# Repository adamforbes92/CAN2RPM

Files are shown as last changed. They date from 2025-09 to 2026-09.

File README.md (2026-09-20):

# CAN2RPM

ESP32-based converter that reads engine RPM from a CAN bus and outputs a traditional coil-type signal for use with MK1/MK2 analog tachometers.

Built around the ESP32 DevKit V1, it captures VAG/ME7.x CAN messages and translates them into a high-voltage square-wave RPM output suitable for clusters that expect a coil ignition pulse.

**Current firmware version: 1.06** — adopts Forbes Automotive's shared Wi‑Fi AP/mDNS manager, two-step OTA updater and Ignitron dark theme, common across the ESP32 product line.

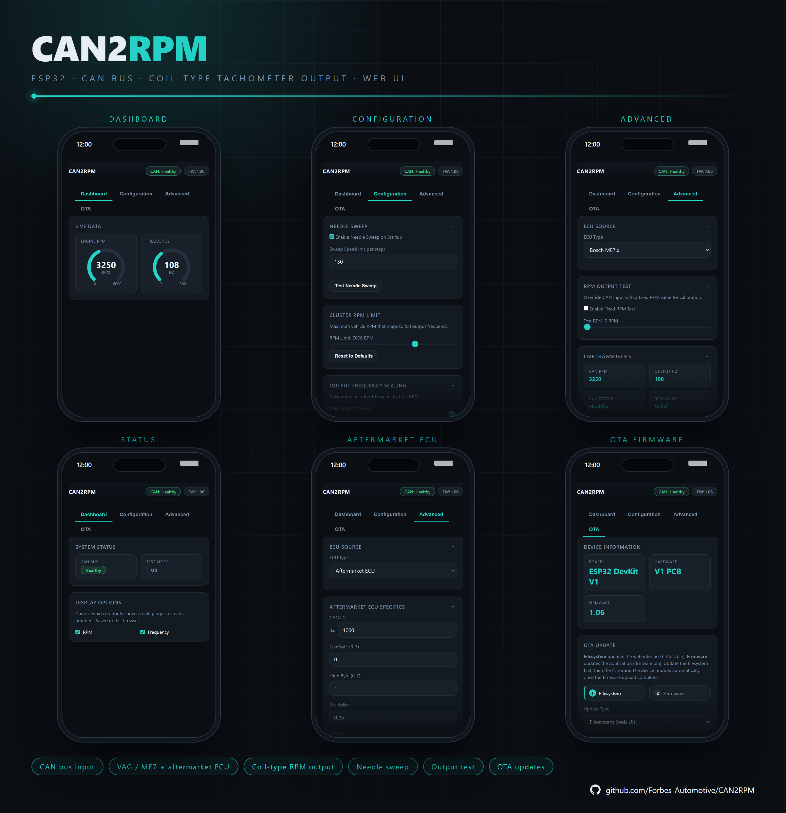
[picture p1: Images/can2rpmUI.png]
CAN2RPM Web UI — dashboard, configuration, advanced, status, aftermarket ECU and OTA


---

## What it does

- Reads **engine RPM** from the chassis CAN bus (500 kbit/s TWAI)
- Outputs a **coil-type RPM signal** on a dedicated pin (high-voltage square wave)
- Supports **aftermarket CAN IDs** with configurable byte mapping and scaling
- Optional **needle sweep** on power-up
- Hosts a **WiFi AP + web UI** for configuration and OTA updates — no laptop or serial cable needed

---

## Hardware

| Function | Detail |
|---|---|
| Board | ESP32 DevKit V1 (`esp32doit-devkit-v1`) |
| CAN transceiver  | SN65HVD230 (3.3 V compatible) |
| RPM output | Coil-type signal on GPIO 26 |
| CAN RX / TX | GPIO 17 / 16 |

---

## Setup

> Connect the module as per the wiring diagram

> Connect to 'CAN2RPM' on WiFi and browse to **192.168.1.1**

> Set the RPM CAN ID and byte positions to match your ECU

> Enable needle sweep if desired

> Save — settings are stored in NVS (EEPROM)

---

## WiFi & Web UI

WiFi is enabled at all times while the unit is powered and a client is connected. Once the last client disconnects the radio turns off automatically (see Power Management below). A power-cycle restores it.

Connect to the **CAN2RPM** access point (open network, `192.168.1.1`) and browse to **192.168.1.1** or **can2rpm.local**.

| Tab | Cards |
|---|---|
| **Dashboard** | **Live Data** — engine RPM and coil output frequency as dial gauges; **System Status** — CAN bus and Test Mode pills; **Display Options** — gauge or numeric per readout |
| **Configuration** | **Needle Sweep** (enable on start-up, ms per step, test button); **Cluster RPM Limit** — the vehicle RPM that maps to full output; **Output Frequency Scaling** — the maximum coil output frequency at full RPM |
| **Advanced** | **ECU Source** — Bosch ME7.x (VAG) or Aftermarket ECU; **Aftermarket ECU Specifics** (shown when Aftermarket is selected) — CAN ID, low / high byte, multiplier and addition; **RPM Output Test** — override the CAN input with a fixed RPM for calibration; **Live Diagnostics** — CAN RPM, output Hz, CAN status and RPM validity |
| **OTA** | Device information and the two-step updater — see below |

<p align="center">
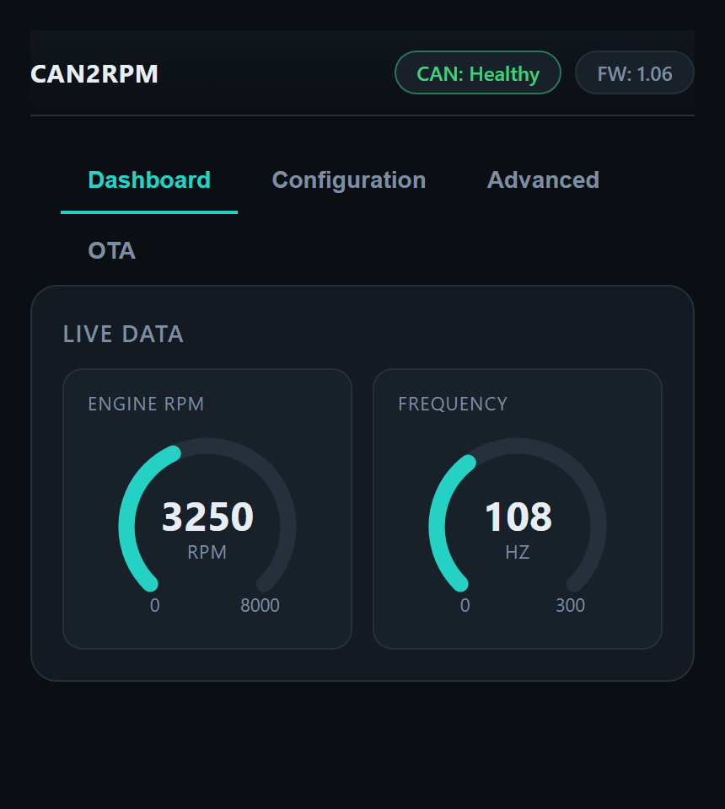
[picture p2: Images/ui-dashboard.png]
Dashboard — engine RPM and output frequency gauges
  
  &nbsp;&nbsp;
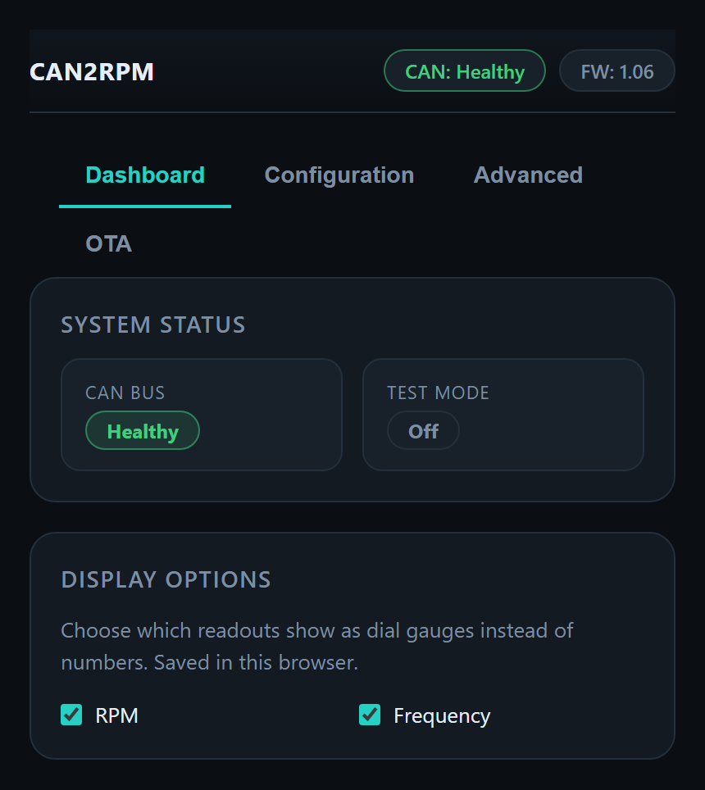
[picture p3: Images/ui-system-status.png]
Dashboard — system status pills (CAN bus, test mode) and display options
  
</p>
<p align="center">
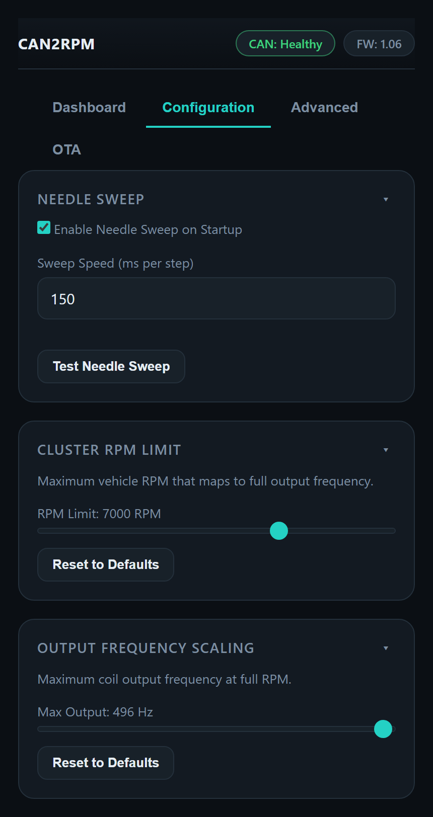
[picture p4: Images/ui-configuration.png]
Configuration — needle sweep, cluster RPM limit and output frequency scaling
  
  &nbsp;&nbsp;
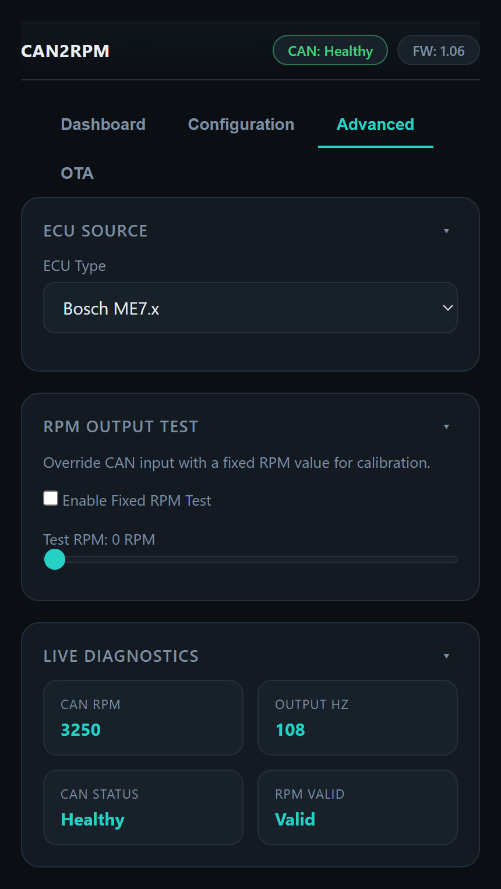
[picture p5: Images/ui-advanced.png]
Advanced — ECU source, RPM output test and live diagnostics
  
</p>
<p align="center">
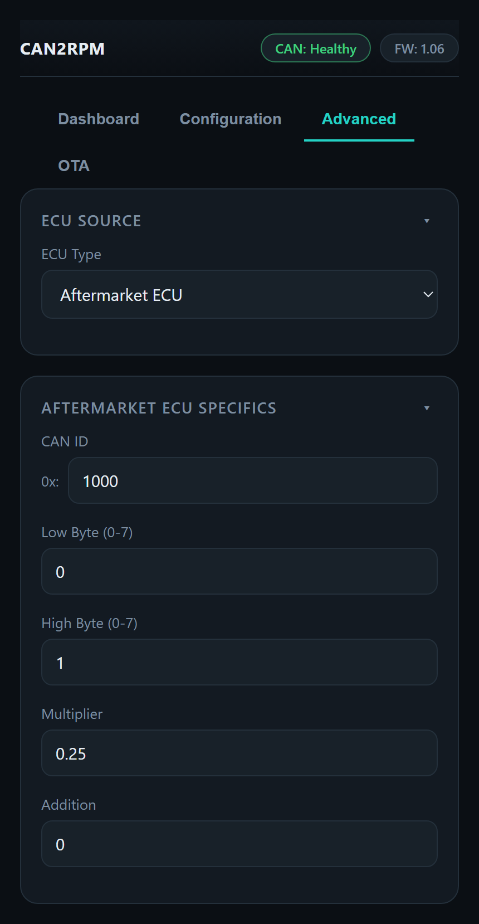
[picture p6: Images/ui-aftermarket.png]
Advanced — ECU source set to Aftermarket ECU, revealing the CAN ID, byte positions, multiplier and addition fields
  
</p>

*Setting the ECU type to **Aftermarket ECU** reveals the byte-mapping card: pick the CAN ID (hex), which two bytes carry RPM, and the multiplier / addition that turn the raw value into RPM.*

### OTA Updates (Two-Step)

CAN2RPM uses Forbes Automotive's shared OTA module. Firmware and web UI are on separate flash partitions, so an update is done in **two steps** from the OTA tab:

1. **Filesystem** — upload `littlefs.bin` (`POST /api/ota/fs`). Updates the web UI (`index.html`, `app.js`, `style.css`). The device does **not** reboot after this step.
2. **Firmware** — upload `firmware.bin` (`POST /api/ota`). Updates the application code and reboots automatically once complete.

The OTA tab shows a "1 Filesystem / 2 Firmware" step indicator so it's clear which upload is in progress. `GET /api/ota/info` reports the running version, board and hardware.

> Download the most recent release `.bin` file(s) from GitHub, connect to CAN2RPM on WiFi, open the OTA tab at 192.168.1.1 (or can2rpm.local), and upload the filesystem image followed by the firmware image.

<p align="center">
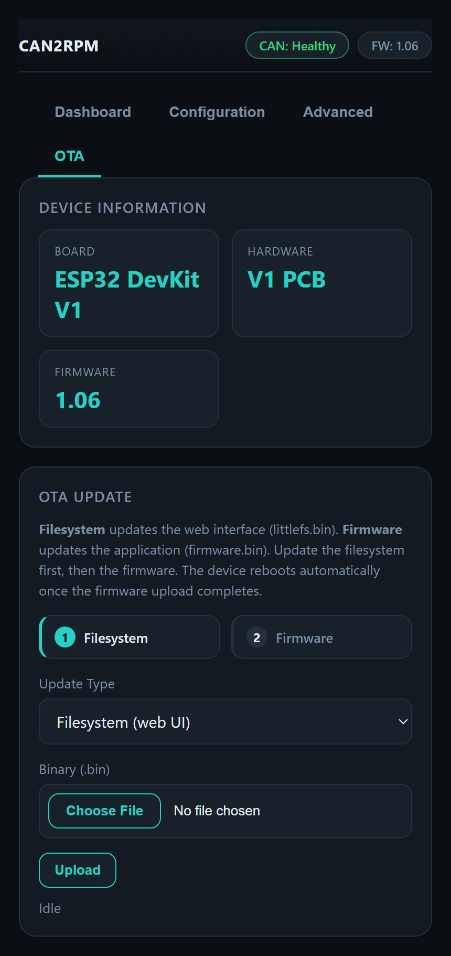
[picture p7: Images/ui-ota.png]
OTA tab — device information and two-step update
  
</p>

---

## Status Indicators

The web UI uses Forbes Automotive's shared dark theme (the same look used across OpenHaldex, Can2Cluster, SpeedPulser, SpeedPulserPro, the MQB Steering Wheel Controller and AirLift Controller), with a consistent colour convention for status pills and badges:

| Colour | Meaning in CAN2RPM |
|---|---|
| 🟢 Green | CAN bus healthy and the displayed RPM/Hz values are live, real data |
| 🔴 Red | CAN bus unhealthy / no signal, or the decoded RPM value isn't yet verified |
| 🟠 Orange | **Test mode is active** — the RPM/Hz readouts are synthetic values generated by the built-in diagnostic test, not real CAN data |

Orange here specifically means "you're looking at test data," so always confirm the Test Mode pill is off before trusting a live reading.

---

## Power Management

The firmware includes a universal reduced-power module that automatically saves current once no clients are connected to the WiFi AP. This directly reduces heat generated by the on-board linear voltage regulator — a linear regulator dissipates heat proportional to `(Vin − Vout) × I_load`, so every milliamp saved is less heat.

**What happens 1 minute after the last client disconnects:**
> WiFi radio off — the single biggest saving (~80–120 mA average)

> CPU frequency scaled: 240 MHz → 80 MHz

> Bluetooth controller disabled at boot (frees ~60 KB RAM)

> Onboard LED off at boot

Everything restores automatically the moment a client reconnects. A power-cycle (ignition off/on) will also bring WiFi back if required.

---

## Build & Flash

PlatformIO project (`platformio.ini`):

```bash
# Build firmware
pio run

# Upload firmware (USB)
pio run -t upload

# Upload web UI (LittleFS)
pio run -t uploadfs
```

---

## Disclaimer

This drives a tachometer but should always be assumed to have some inaccuracy. Forbes Automotive accepts no responsibility for speed or RPM related incidents.

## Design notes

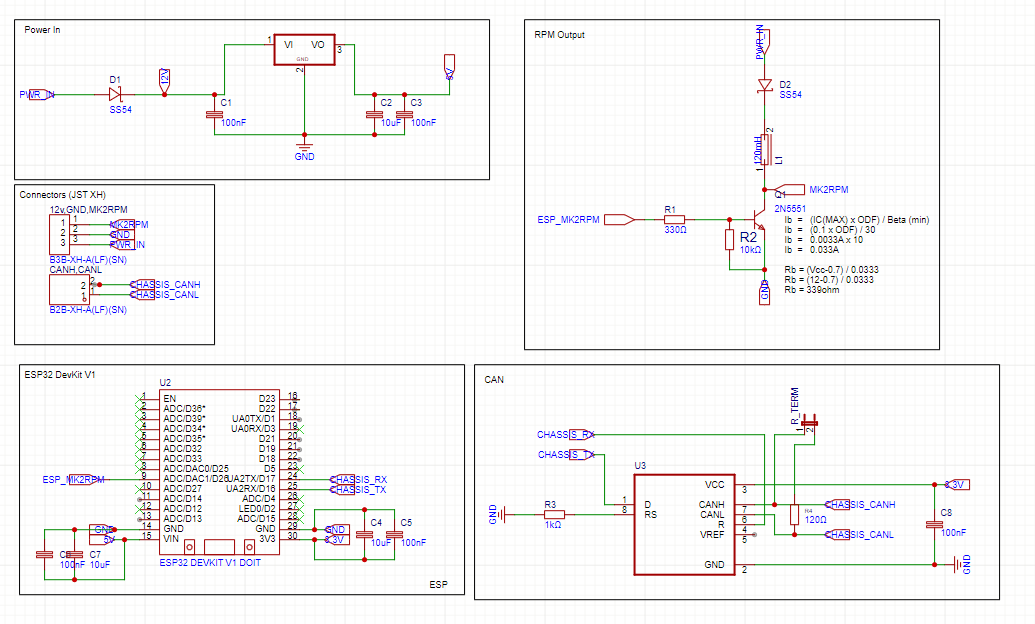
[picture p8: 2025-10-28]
Images/Schematic.png

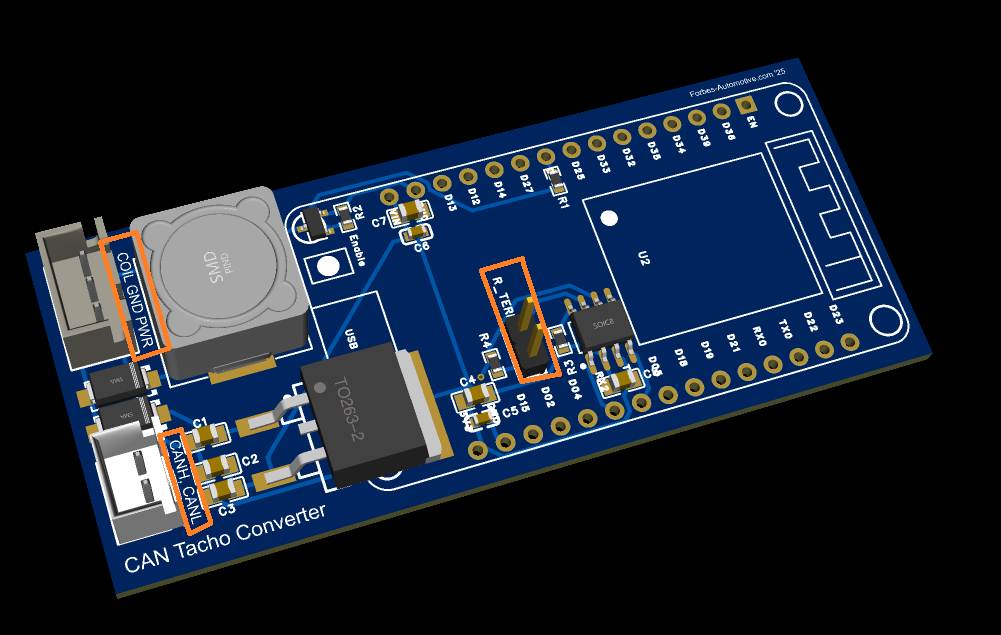
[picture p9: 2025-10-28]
Images/BoardOverview.png

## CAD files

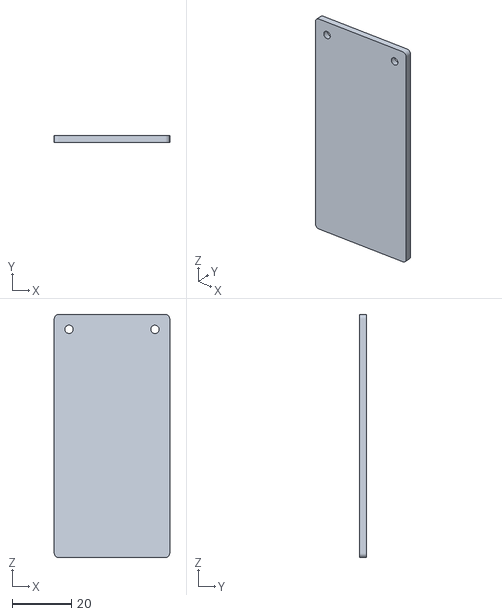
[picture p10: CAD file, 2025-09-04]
Enclosure/Can2RPMLid.STL
39.0 x 2.40 x 82.0

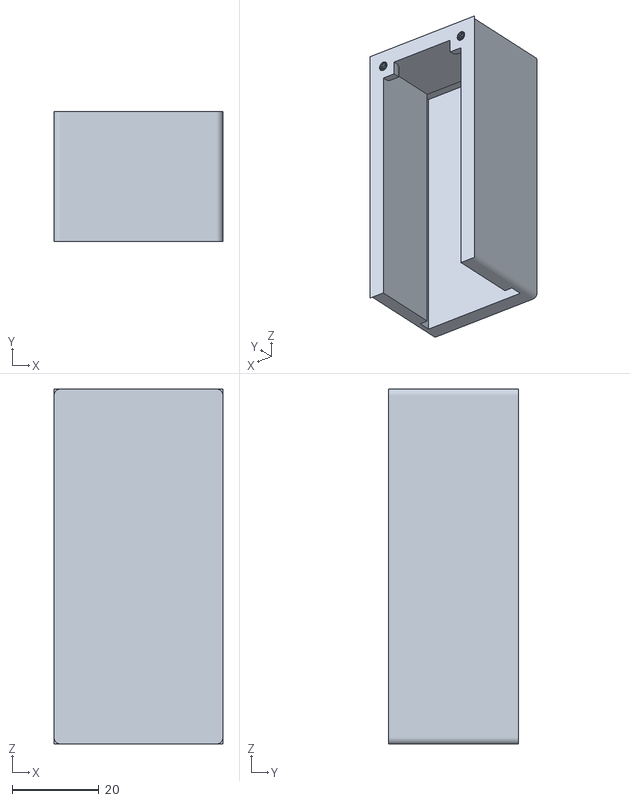
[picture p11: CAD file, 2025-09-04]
Enclosure/Can2RPM.STL
39.0 x 30.0 x 82.0

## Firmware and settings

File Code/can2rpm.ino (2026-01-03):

/* 
Basic CAN-BUS converter to coil based output.  Used for MK2 'analog' clusters in ME7.x and aftermarket conversions.
Forbes-Automotive, 2025
*/

// for CAN
#include "can2rpm_defs.h"
ESP32_CAN<RX_SIZE_256, TX_SIZE_16> chassisCAN;             // CAN Lib
TickTwo tickEEP(writeEEP, eepRefresh);                     // timer for EEPROM saving
TickTwo tickError(checkError, 500);                        // timer for error checking
TickTwo tickWiFi(disconnectWifi, wifiDisable);             // timer for disconnecting wifi after 30s if no connections - saves power
TickTwo tickWiFiConn(checkConnections, wifiDisable / 30);  // timer for checking wifi connections.  If > 0, flash the onboard LED
Preferences pref;                                          // for EEPROM / saving preferences

// define one hardware timers for RPM output
hw_timer_t* timer0 = NULL;

bool rpmTrigger = true;
long frequencyRPM = 20;  // 20 to 20000

// timer for RPM
void IRAM_ATTR onTimer0() {
  rpmTrigger = !rpmTrigger;
  digitalWrite(pinCoil, rpmTrigger);  // flip-flop RPM trigger to create pulse
}

// setup timers
void setupTimer() {
  timer0 = timerBegin(0, 40, true);  //div 80
  timerAttachInterrupt(timer0, &onTimer0, true);
}

// adjust output frequency
void setFrequencyRPM(long frequencyHz) {
  if (frequencyHz != 0) {
    timerAlarmDisable(timer0);
    timerAlarmWrite(timer0, 1000000l / frequencyHz, true);
    timerAlarmEnable(timer0);
  } else {
    timerAlarmDisable(timer0);  // error catch, if freq. set to zero
  }
}

void setup() {
  readEEP();        // read the EEPROM for previous states
  tickEEP.start();  // begin ticker for the EEPROM
  tickError.start();
  tickWiFi.start();      // begin ticker for the WiFi (to turn off after 60s)
  tickWiFiConn.start();  // begin ticker to check the number of WiFi connections (to flash the onboard LED)

  basicInit();   // basic init for setting up IO / CAN
  setupTimer();  // setup the timers (with a base frequency)

  if (hasNeedleSweep) {
    needleSweep();  // carry out needle sweep if enabled
  }

  connectWifi();         // enable / start WiFi
  WiFi.setSleep(false);  // for the ESP32: turn off sleeping to increase UI responsivness (at the cost of power use)
  setupUI();             // setup wifi user interface
}

void loop() {
  // get the easy stuff out the way first
  tickEEP.update();  // refresh the EEP ticker
  tickError.update();
  tickWiFi.update();      // refresh the WiFi ticker
  tickWiFiConn.update();  // refresh the WiFi connection ticker

  if (tempNeedleSweep) {
    // can't do this in the WiFi loop - so set flag in there and process here
    needleSweep();
    tempNeedleSweep = false;  // reset to false to stop it continuing to run
  }

  // if last CAN message was >500ms ago, it's in an error state, set flag
  if ((millis() + 10 - lastCAN) > 500) {
    hasError = true;
    ESPUI.updateLabel(label_hasCAN, "No");
    ESPUI.updateLabel(label_RPMCAN, "CAN RPM: 0");
    vehicleRPM = 0;
  } else {
    hasError = false;
    ESPUI.updateLabel(label_hasCAN, "Yes");
    char buf[32];
    sprintf(buf, "CAN RPM: %d", vehicleRPM);
    ESPUI.updateLabel(label_RPMCAN, String(buf));
  }

  if ((millis() + 10 - lastMillis) > rpmDelay) {  // check to see if x ms (rpmDelay) has elapsed - slow down the RPM changes!
    lastMillis = millis();

    // diagTest is in 'WiFi' and will allow the user to set a fixed RPM for calibration
    if (tempDiagTest) {
      frequencyRPM = map(tempRPM, 0, clusterRPMLimit, 0, maxRPM);
      setFrequencyRPM(frequencyRPM);  // minimum speed may command 0 and setFreq. will cause crash, so +1 to error 'catch'
    } else {
      // calculate final frequency for RPM:
      frequencyRPM = map(vehicleRPM, 0, clusterRPMLimit, 0, maxRPM);
      setFrequencyRPM(frequencyRPM);  // minimum speed may command 0 and setFreq. will cause crash, so +1 to error 'catch'
    }
  }
}

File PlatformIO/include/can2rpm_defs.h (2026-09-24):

#pragma once

#include <Arduino.h>
#include "driver/twai.h"
#include "driver/ledc.h"
#include <Preferences.h>
#include <ESPAsyncWebServer.h>
#include <AsyncJson.h>
#include <LittleFS.h>
#include <WiFi.h>
#include <ArduinoJson.h>
#include <Update.h>

// ─────────────────────────────────────────────────────────────────
// Debug flags  (0 = off, 1 = on)
// ─────────────────────────────────────────────────────────────────
#define ChassisCANDebug  0   // print raw CAN frames to Serial
#define serialDebug      0   // general Serial talkback
#define serialDebugWifi  0   // WiFi / API Serial talkback

#define wifiHostName  "CAN2RPM"
#define eepRefresh    5000     // EEPROM save interval (ms)

#define pinRX_CAN   17   // SN65HVD230 CAN_RX
#define pinTX_CAN   16   // SN65HVD230 CAN_TX
#define pinCoil     26   // coil trigger output (RPM)
#define onboardLED   2   // on-board LED

#define baudSerial  115200

#define rpmDelay  20   // RPM output update interval (ms)

#define MOTOR1_ID       0x280
#define AFTERMARKET_ID  0x1001

#if serialDebug
  #define DEBUG_PRINT(x)        Serial.print(x)
  #define DEBUG_PRINTLN(x)      Serial.println(x)
  #define DEBUG_PRINTF(fmt,...) Serial.printf(fmt, ##__VA_ARGS__)
#else
  #define DEBUG_PRINT(x)
  #define DEBUG_PRINTLN(x)
  #define DEBUG_PRINTF(fmt,...)
#endif

#if ChassisCANDebug
  #define CAN_DEBUG_PRINT(x)        Serial.print(x)
  #define CAN_DEBUG_PRINTLN(...)    Serial.println(##__VA_ARGS__)
  #define CAN_DEBUG_PRINT_HEX(x)    Serial.print(x, HEX)
#else
  #define CAN_DEBUG_PRINT(x)
  #define CAN_DEBUG_PRINTLN(...)
  #define CAN_DEBUG_PRINT_HEX(x)
#endif

extern bool     selfTest;
extern bool     hasNeedleSweep;
extern uint8_t  sweepSpeed;
extern uint16_t maxRPM;
extern uint16_t clusterRPMLimit;
extern uint16_t tempRPM;

extern uint8_t  ecuMode;               // 0 = Bosch ME7.x, 1 = Aftermarket ECU
extern uint32_t aftermarketCanId;      // CAN ID used for aftermarket RPM frame
extern uint8_t  aftermarketByteLow;    // low-byte index (0..7)
extern uint8_t  aftermarketByteHigh;   // high-byte index (0..7)
extern int32_t  aftermarketMultiplierFx; // fixed-point multiplier (value * 1000)
extern int16_t  aftermarketAddition;   // offset added after scaling

extern const int32_t aftermarketMultiplierScale;

extern volatile uint16_t vehicleRPM;
extern volatile uint32_t lastCAN;
extern volatile bool     rpmTruth;
extern volatile bool     canHealthy;

extern bool     hasError;
extern bool     triggerLED;
extern bool     tempNeedleSweep;
extern bool     needleSweepInProgress;
extern bool     tempDiagTest;
extern uint32_t lastMillis;

extern long        frequencyRPM;

extern const ledc_mode_t      rpmLedcMode;
extern const ledc_timer_t     rpmLedcTimer;
extern const ledc_channel_t   rpmLedcChannel;
extern const ledc_timer_bit_t rpmLedcResolution;
extern const uint32_t         rpmLedcMinFreqHz;
extern const uint32_t         rpmLedcLatchFreqHz;
extern const uint32_t         rpmLedcDutyOff;
extern const uint32_t         rpmLedcDuty50;

extern TaskHandle_t updateRPMHandle;
extern Preferences    pref;
extern AsyncWebServer server;

// io / main
void setupTimer();
void setFrequencyRPM(long frequencyHz);
void basicInit();
void setupPins();
void needleSweep();
void checkError();

// can
void canInit();
void startCanReceiveTask();
void onBodyRX(const twai_message_t& msg);

// eep
void readEEP();
void writeEEP();

// wifi
void connectWifi();
void checkConnections();
void setupUI();
void generalCallback(const String& key, const String& value);
void extendedCallback(const String& action);

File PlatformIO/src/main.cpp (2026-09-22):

/*
Basic CAN-BUS converter to coil-based RPM output.
Used for MK2 'analog' clusters with ME7.x and aftermarket conversions.
Forbes-Automotive, 2026
*/

#include "can2rpm_defs.h"
#include "can2rpm_vers.h"
#include "can2rpm_tasks.h"
#include "power_manager.h"
#include "wifi_manager.h"

void setup() {
    readEEP(); // read settings from NVS before anything else, as they affect init behaviour

    basicInit(); // Serial, pins, CAN, timer
    setupTimer(); // LEDC timer and channel for RPM output

    if (hasNeedleSweep) {
        needleSweep(); // perform initial needle sweep if enabled (before WiFi so it doesn't block UI)
    }

    connectWifi();
    setupUI();

    // Universal reduced-power module: turns WiFi off 1 min after the last client
    // disconnects, scales CPU 240->80 MHz, releases Bluetooth and kills the
    // onboard LED to cut current draw (and therefore linear-regulator heat).
    power_config_t pcfg = powerDefaultConfig();
    pcfg.verbose = serialDebugWifi;
    powerInit(&pcfg);

    startTasks();   // start all background RTOS tasks
}

void loop() {
    // Needle sweep requested from API
    if (tempNeedleSweep) {
        needleSweep(); 
        tempNeedleSweep = false;
    }
    wifiManagerTick(); // Home WiFi (bridge mode): connection tracking + retry back-off
    vTaskDelay(pdMS_TO_TICKS(100));
}

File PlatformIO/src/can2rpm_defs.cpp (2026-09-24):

#include "can2rpm_defs.h"

// ─────────────────────────────────────────────────────────────────
// Global variable definitions
// ─────────────────────────────────────────────────────────────────
bool     selfTest        = false;   // self-test mode
bool     hasNeedleSweep  = false;   // perform needle sweep on boot
uint8_t  sweepSpeed      = 18;      // needle sweep step delay (ms)
uint16_t maxRPM          = 230;     // maximum output frequency (Hz)
uint16_t clusterRPMLimit = 7000;    // vehicle RPM that maps to maxRPM
uint16_t tempRPM         = 3000;    // fixed RPM used in diag test mode

uint8_t  ecuMode              = 0;          // default: Bosch ME7.x
uint32_t aftermarketCanId     = AFTERMARKET_ID;
uint8_t  aftermarketByteLow   = 2; // low byte
uint8_t  aftermarketByteHigh  = 3; // high byte
int32_t  aftermarketMultiplierFx = 1000; // fixed-point multiplier; 1000 == 1.000
int16_t  aftermarketAddition  = 0; // offset added after scaling (after byte extraction)

const int32_t aftermarketMultiplierScale = 1000;

volatile uint16_t vehicleRPM = 0;   // current engine RPM from CAN
volatile uint32_t lastCAN    = 0;   // millis() timestamp of last CAN frame
volatile bool     rpmTruth   = false; // true when decoded RPM is in accepted range
volatile bool     canHealthy = false; // true when CAN frames are being received within timeout

bool     hasError        = false;   // CAN timeout / error state
bool     triggerLED      = false;   // LED blink toggle state
bool     tempNeedleSweep = false;   // flag: trigger needle sweep from web UI
bool     needleSweepInProgress = false; // flag: prevent overlapping sweeps
bool     tempDiagTest    = false;   // flag: use fixed tempRPM instead of CAN RPM
uint32_t lastMillis      = 0;       // RPM output rate-limiter timestamp

long        frequencyRPM = 0;      // current output frequency (Hz)

const ledc_mode_t      rpmLedcMode       = LEDC_LOW_SPEED_MODE;
const ledc_timer_t     rpmLedcTimer      = LEDC_TIMER_0;
const ledc_channel_t   rpmLedcChannel    = LEDC_CHANNEL_0;
const ledc_timer_bit_t rpmLedcResolution = LEDC_TIMER_10_BIT;
const uint32_t         rpmLedcMinFreqHz  = 10;
const uint32_t         rpmLedcLatchFreqHz= 5000; // duty changes are latched at this rate - see setFrequencyRPM()
const uint32_t         rpmLedcDutyOff    = 0;
const uint32_t         rpmLedcDuty50     = 512;

TaskHandle_t updateRPMHandle = NULL;

Preferences    pref;
AsyncWebServer server(80);

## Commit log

2025-08-22 Gerber
    Gerber
2025-09-04 Added enclosures
    [Can2RPM.STL, Can2RPMLid.STL]
2025-10-28 Board
    Board
2026-01-03 V1.04
    Error on WiFi boot - delayed for no reason
    [can2rpm.ino, can2rpm_can.ino, can2rpm_defs.h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]
2026-01-24 V1.02
    Added new 4 layer board
2026-10-12 V1.08
    C3 board update (and bring both firmwares inline).
